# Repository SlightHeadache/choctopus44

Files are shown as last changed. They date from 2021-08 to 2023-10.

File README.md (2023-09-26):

# Choctopus44

*Current version: 2.0*

Choctopus44 is low profile, Choc spaced, optionally hotswappaple 44-key column staggered keyboard with a rotary encoder.
It is loosely based on **[gtips's REVIUNG project](https://github.com/gtips/reviung)**, specifically REVIUNG41, but has deviated from it significantly during its development.

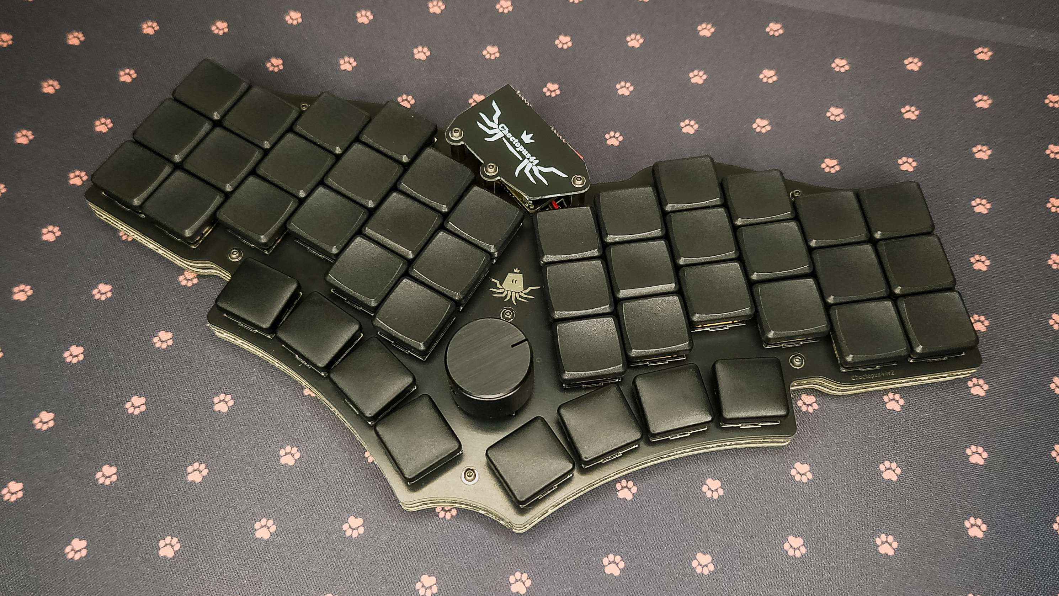
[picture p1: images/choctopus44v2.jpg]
choctopus44


## Known issues with v2

While all the main issues of the original Choctopus44 prototypes were addressed during the development of v2, some new minor arose during it's development.

  * Switch plate does not accommodate all encoders properly. Certain non-Alps THD encoders, and SMD encoders may require filing the plate's encoder cut out to be a little bigger.
    See **[encoder documentation](documents/encoder.md)**.
  * Flaky Bluetooth behaviour in certain edge cases while using Nice!Nano, seems like certain devices don't like Nice!Nano's/ZMK's Bluetooth handling
  * During fabrication with tented vias the battery circuit vias can easily remain exposed, at least with JLCPCB. By my understanding this is caused by the solder mask liquid seeping
    into the via's hole. This doesn't seem to affect other vias as only the battery vias are slightly larger than usual. This should be avoidable by using plugged vias instead, but as
    that increases the cost of manufacturing I'm going to create a hotfix version in the future that shrinks those vias to the standard size to alleviate the issue.

## TODO

  * Add documentation for v2's plate and bottom foams

## Parts list

### Main components

| Part | Count | Optional | Notes |
| --- |:---:|:---:|:-----:|
| PCB | 1 | | |
| Diode [1N4148 SMD or THD] | 45 | | |
| Kailh Choc sockets | 44 | x | |
| Tactile switch TL3342 or compatible | 1 | | Stem height of 1.54mm used in tested builds |
| Slide switch PCM12 or compatible | 1 | x | Only useful if a wireless microcontroller is used in conjunction with a battery |
| EC11 encoder or compatible | 1 | x | See detailed **[encoder documentation](documents/encoder.md)**; Can also be replaced with a Choc or an MX switch |
| ProMicro/Nice!Nano or compatible | 1 | | |
| MCU socket (or header rows) | 1 (2) | x | |
| Kailh Choc key switch | 44 (45) | | |
| 3.7 Volt battery | 1 | x | Only useful if a wireless microcontroller is used |
| 100 nF capacitors (axial or 1206 SMD) | 2 | x | Used in the optional encoder filter circuit |
| 10 kOhm resistors (axial or 1206 SMD) | 4 | x | ***Not adviced!*** Can be used in the encoder filter circuit, but can cause issues at least with Nice!Nanos |

### Case hardware

| Part | Count | Optional | Notes |
| --- |:---:|:---:|:-----:|
| Top plate [PCB] | 1 | | |
| Bottom plate [PCB] | 1 | | |
| M2 stand off 5mm | 9 | | |
| M2 screw 3mm | 15 (18) | | 18 needed if MCU cover is not used |
| Rubber bump ons | ~11 | | Depending on your bump ons you might need to use more, or get away with using fewer |

### Example extra case hardware if using MCU cover

**Note:** The length of the required MCU cover stand-offs is highly dependant on the used battery and its orientation (assuming one is used at all), and the used MCU socket.
With the listed screws and stand offs, a 5mm thick battery can fit between the MCU and the MCU cover without much issue as long as the the MCU socket is slim enough.

| Part | Count | Optional | Notes |
| --- |:-----:|:---:|:-----:|
| M2 stand off 10mm | 3 | | |
| M2 screw 10mm | 3 | | Used for the bottom plate stand offs; 3mm screws used on the MCU cover |

### Misc hardware

| Part | Count | Optional | Notes |
| --- |:---:|:---:|:-----:|
| Choc spacing compatible keycaps (e.g. MBK) | 44 (45) | | |

## Firmware

***Please note!*** Should you utilize a pre-existing QMK/Vial/ZMK set up, you may need to do additional steps not defined here before you can succesfully build the firmware.
Whether or not that's required is highly dependant on the version and the state of your pre-existing set up!

*Pre-built binaries TBA*

 * QMK: https://github.com/SlightHeadache/qmk_firmware : branch `choctopus_project`
   * If you want to utilize your existing QMK set up, navigate to it and run the following `bash` command to fetch and switch to the WIP branch.
     If you are using git via PowerShell or Windows CMD, remember to switch the `&&`s to semicolons. 
     Remember to switch to your preferred local branch if you wish to meddle with other keyboards.
     ```sh
     git remote add choctopus_project git@github.com:SlightHeadache/qmk_firmware.git && git fetch choctopus_project && git checkout --track -b choctopus_project choctopus_project/choctopus_project
     ```
 * Vial: https://github.com/SlightHeadache/vial-qmk : branch `choctopus44-vial`
   * If you want to utilize your existing Vial set up, navigate to it and run the following `bash` command to fetch and switch to the WIP branch.
     If you are using git via PowerShell or Windows CMD, remember to switch the `&&`s to semicolons. 
     Remember to switch to your preferred local branch if you wish to meddle with other keyboards.
     ```sh
     git remote add choctopus44-vial git@github.com:SlightHeadache/vial-qmk.git && git fetch choctopus44-vial && git checkout --track -b choctopus44-vial choctopus44-vial/choctopus44-vial
     ```
 * ZMK: https://github.com/SlightHeadache/zmk : branch `choctopus44`
   * For an easy online build using GitHub actions, fork https://github.com/SlightHeadache/zmk-config and enable Actions from *Settings -> Actions -> Allow all actions*. Then clone your fork.
     The keymap file can be found from path `config/boards/shields/choctopus44/choctopus44.keymap` in the cloned repo. The firmware should now build automagically when you push your keymap changes to GitHub.
     The built firmware can be found from under the GitHub Actions run's summary (e.g. https://github.com/SlightHeadache/zmk-config/actions/runs/6002979887), *not* under either of the build steps.
   * If you want to utilize your existing ZMK set up, navigate to it and run the following `bash` command to fetch and switch to the WIP branch.
     If you are using git via PowerShell or Windows CMD, remember to switch the `&&`s to semicolons. 
     Remember to switch to your preferred local branch if you wish to meddle with other keyboards.
     ```sh
     git remote add choctopus44 git@github.com:SlightHeadache/zmk.git && git fetch choctopus44 && git checkout --track -b choctopus44 choctopus44/choctopus44
     ```

## Build guide

See [build guide](documents/buildguide.md).

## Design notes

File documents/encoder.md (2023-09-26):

# Encoder footprint

## Compatibility

The center encoder footprint in the Choctopus is compatible with EC11 style encoders (both SMD and THD), MX type switches, and Choc switches.
However, certain encoder versions might have issues with the encoder cut out in the switch plate. For example, many SMD encoders and certain THD encoders
with large bodies may not fit the plate cut out properly requiring you to file the plate cut out a bit.
SMD encoders also require you to flatten out the side support legs so that they do not conflict with the switch plate.
Should you do so, please take proper safety percautions, as breathing in FR4 dust is not recommended.

The plan is to slightly adjust the encoder cut out size in version 2.1 to properly accomodate large body encoders. However, even after that SMD encoder
side support legs will still require bending.

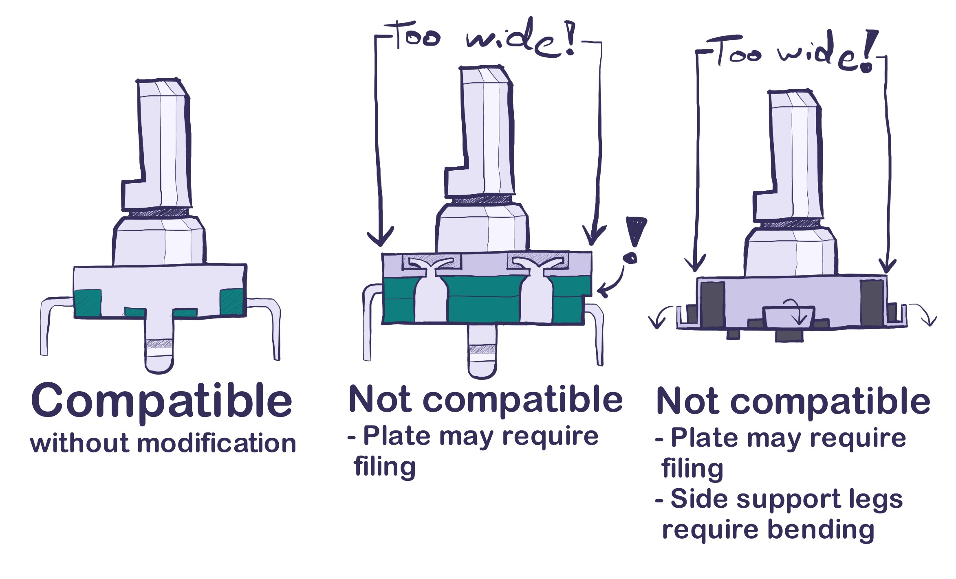
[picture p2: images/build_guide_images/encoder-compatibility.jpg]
encoder compatibility


Largest compatible encoder knob radius is 15mm, though personally I'd recommend going a good bit smaller than that for greater comfort.
However, this is very much down to encoder choise and preference, heavy encoders might be much easier to use with bigger knobs, but lighter ones might be
inconveniently easy to actuate with a large knob.

## Filtering circuit

The encoder footprint is attached to a encoder filtering circuit.
This is intended to improve performance and reliability with lower quality encoders which are not that uncommon.
However, after some very minor testing while building an unit or two it looks like the filtering circuit is largely useless, or even downright harmful for the user experience.
At least based on my testing it looks like ZMK and Nice!Nano do not play nicely with the filtering circuit in it's full configuration,
and that the resistors of the full filter circuit essentially end up disabling it as a whole.
Could be that this is entirely dependant on the values used for the circuit, but at least with 10 kOhm resistors and 100 nF capacitors I had no luck.

In normal operation I would highly recommend just bridging the jumpers that circumvent the filter circuit entirely.
However, based on some rudimentary testing, soldering the capacitors into place may still increase the reliability of the encoder.
At least in my personal board soldering those on seemed to increase the reliability of the encoder from roughly ~95% to ~100%.

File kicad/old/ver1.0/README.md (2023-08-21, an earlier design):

# Note!

This version of the PCB has a lot of problems and is deprecated.

The battery routing issue should be addressed in the latest commit, though that is untested. The USB collision issue still remains.

usb collision issue

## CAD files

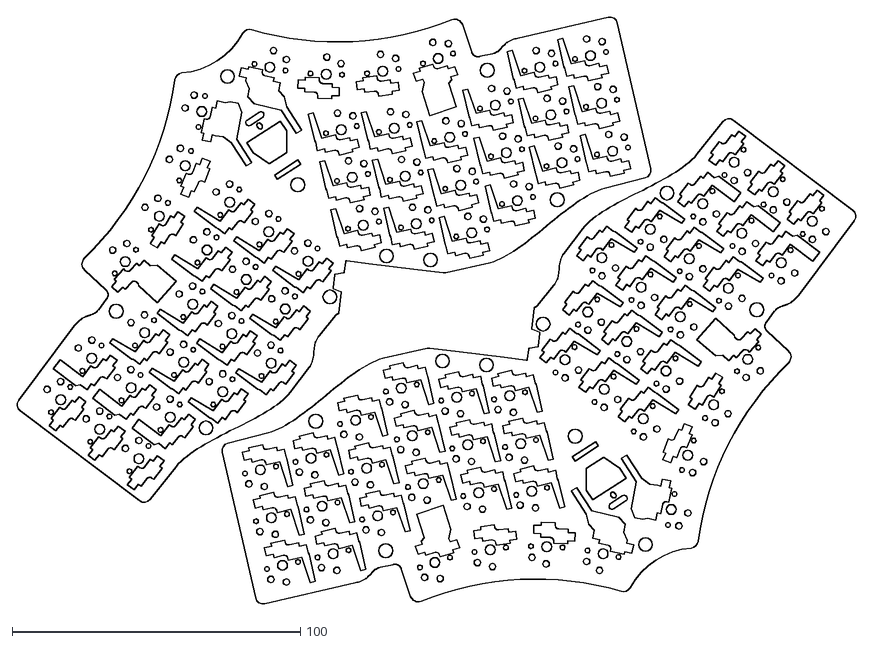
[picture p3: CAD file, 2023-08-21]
kicad/ver2.0/choctopus44-bottom-filler/A4-laser/choctopus44-bottom-filler-Edge_Cuts.dxf
291.7 x 204.0

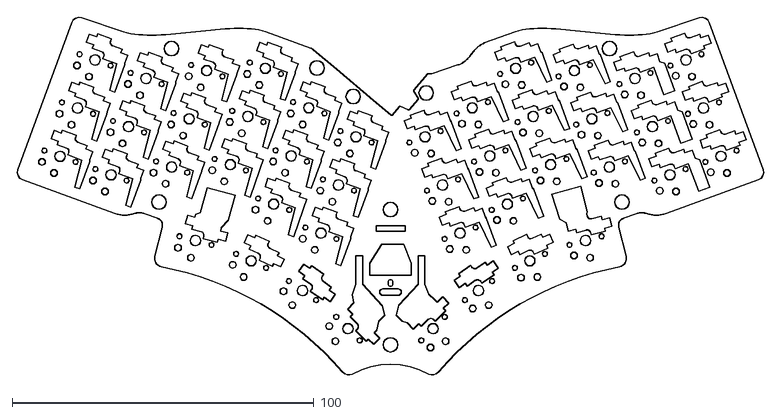
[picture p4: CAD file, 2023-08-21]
kicad/ver2.0/choctopus44-bottom-filler/choctopus44-bottom-filler-Edge_Cuts.dxf
248.1 x 119.1

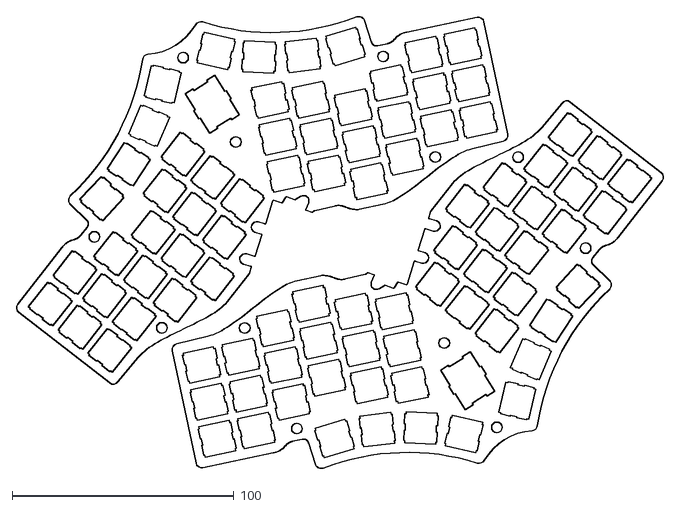
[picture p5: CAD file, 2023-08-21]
kicad/ver2.0/choctopus44-top-filler/A4-laser/choctopus44-top-filler-Edge_Cuts.dxf
292.0 x 203.8

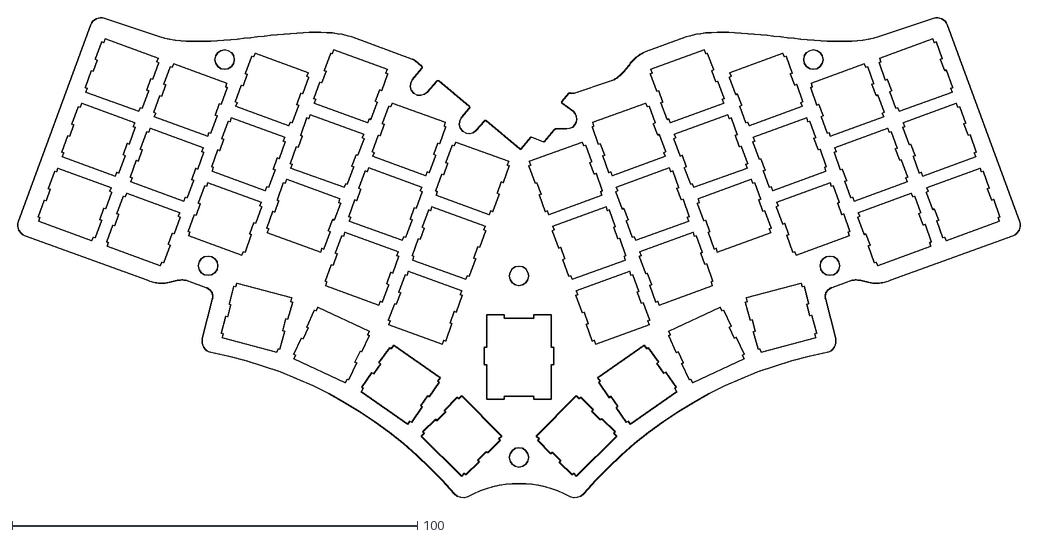
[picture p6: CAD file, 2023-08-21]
kicad/ver2.0/choctopus44-top-filler/choctopus44-top-filler-Edge_Cuts.dxf
248.1 x 119.1

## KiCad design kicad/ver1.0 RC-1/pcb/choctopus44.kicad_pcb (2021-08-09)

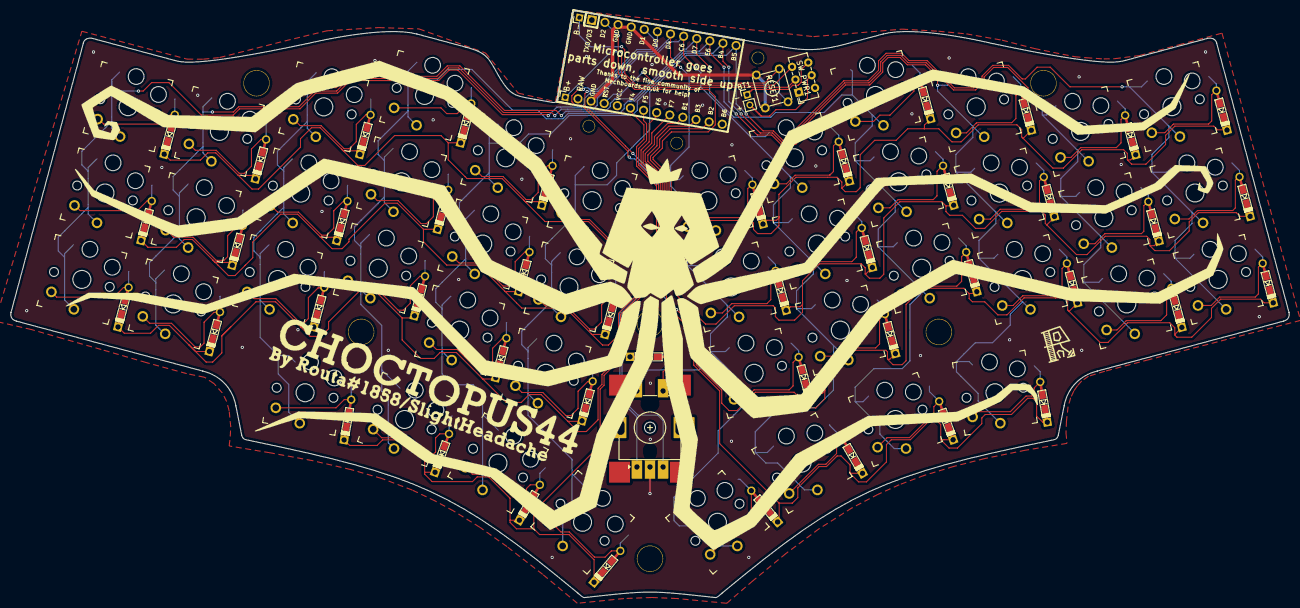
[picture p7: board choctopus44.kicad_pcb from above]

Board: 2 copper layers, 243.9 x 111.9 mm, 105 parts (1 on the bottom side), 67 nets.

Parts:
B+: PinHeader_1x01_P2.00mm_Vertical
B-: PinHeader_1x01_P2.00mm_Vertical
BT1: Battery_Cell; PinHeader_1x02_P2.00mm_Vertical
D1, D2, D3, D4, D5, D6, D7, D8, D9, D10, D11, D12, D13, D14, D15, D16, D17, D18, D19, D20, D21, D22, D23, D24, D25, D26, D27, D28, D29, D30, D31, D32, D33, D34, D35, D36, D37, D38, D39, D40, D41, D42, D43, D44, D45: 1N4148W; Diode-dual
H1: H1; HOLE
H6, H6#2: H6; HOLE
H8, H8#2: H8; HOLE
H11: H11; HOLE
H12: H12; HOLE_2.2mm
H13: H13; HOLE_2.2mm
H14: H14; HOLE_2.2mm
RESET1: SW_PUSH; SW_TH_Tactile_Omron_B3F-10xx
SW1, SW2, SW3, SW4, SW5, SW6, SW7, SW8, SW9, SW10, SW11, SW12, SW13, SW14, SW15, SW16, SW17, SW18, SW19, SW20, SW21, SW22, SW23, SW24, SW25, SW26, SW27, SW28, SW29, SW30, SW31, SW32, SW33, SW34, SW35, SW36, SW37, SW38, SW39, SW40, SW41, SW42, SW43, SW44: SW_PUSH; Kailh_socket_PG1350_optional
SW45: Rotary_Encoder_Switch; RotaryEncoder_Alps_EC11E-Switch_Vertical_H20mm-SMD-support
SW_PWR1: SW_DPST; SW_E-Switch_EG1271_DPDT
U1: ProMicro; ArduinoProMicro

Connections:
+BATT: B+.1, SW_PWR1.1
-BATT: B-.1, SW_PWR1.3
Enc1A: SW45.A, U1.5
Enc1B: SW45.B, U1.6
GND: RESET1.3, RESET1.4, SW45.C, U1.3, U1.4, U1.23
unnamed: BT1.1, SW_PWR1.4
unnamed: BT1.2, SW_PWR1.2
unnamed: D1.2, SW1.2
unnamed: D2.2, SW2.2
unnamed: D3.2, SW3.2
unnamed: D4.2, SW4.2
unnamed: D5.2, SW5.2
unnamed: D6.2, SW6.2
unnamed: D7.2, SW7.2
unnamed: D8.2, SW8.2
unnamed: D9.2, SW9.2
unnamed: D10.2, SW10.2
unnamed: D11.2, SW11.2
unnamed: D12.2, SW12.2
unnamed: D13.2, SW13.2
unnamed: D14.2, SW14.2
unnamed: D15.2, SW15.2
unnamed: D16.2, SW16.2
unnamed: D17.2, SW17.2
unnamed: D18.2, SW18.2
unnamed: D19.2, SW19.2
unnamed: D20.2, SW20.2
unnamed: D21.2, SW21.2
unnamed: D22.2, SW22.2
unnamed: D23.2, SW23.2
unnamed: D24.2, SW24.2
unnamed: D25.2, SW25.2
unnamed: D26.2, SW26.2
unnamed: D27.2, SW27.2
unnamed: D28.2, SW28.2
unnamed: D29.2, SW29.2
unnamed: D30.2, SW30.2
unnamed: D31.2, SW31.2
unnamed: D32.2, SW32.2
unnamed: D33.2, SW33.2
unnamed: D34.2, SW34.2
unnamed: D35.2, SW35.2
unnamed: D36.2, SW36.2
unnamed: D37.2, SW37.2
unnamed: D38.2, SW38.2
unnamed: D39.2, SW39.2
unnamed: D40.2, SW40.2
unnamed: D41.2, SW41.2
unnamed: D42.2, SW42.2
unnamed: D43.2, SW43.2
unnamed: D44.2, SW44.2
unnamed: D45.2, SW45.S1
col0: SW1.1, SW7.1, SW13.1, SW19.1, SW25.1, SW31.1, SW41.1, SW45.S2, U1.7
col1: SW2.1, SW8.1, SW14.1, SW20.1, SW26.1, SW32.1, SW42.1, U1.8
col2: SW3.1, SW9.1, SW15.1, SW21.1, SW27.1, SW33.1, SW37.1, SW43.1, U1.9
col3: SW4.1, SW10.1, SW16.1, SW22.1, SW28.1, SW34.1, SW38.1, SW44.1, U1.10
col4: SW5.1, SW11.1, SW17.1, SW23.1, SW29.1, SW35.1, SW39.1, U1.11
col5: SW6.1, SW12.1, SW18.1, SW24.1, SW30.1, SW36.1, SW40.1, U1.12
reset: RESET1.1, RESET1.2, U1.22
row0: D1.1, D2.1, D3.1, D4.1, D5.1, D6.1, U1.20
row1: D7.1, D8.1, D9.1, D10.1, D11.1, D12.1, U1.19
row2: D13.1, D14.1, D15.1, D16.1, D17.1, D18.1, U1.18
row3: D19.1, D20.1, D21.1, D22.1, D23.1, D24.1, U1.17
row4: D25.1, D26.1, D27.1, D28.1, D29.1, D30.1, U1.16
row5: D31.1, D32.1, D33.1, D34.1, D35.1, D36.1, U1.15
row6: D37.1, D38.1, D39.1, D40.1, D45.1, U1.14
row7: D41.1, D42.1, D43.1, D44.1, U1.2

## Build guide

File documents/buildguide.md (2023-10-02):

# Choctopus44v2 - Build Guide

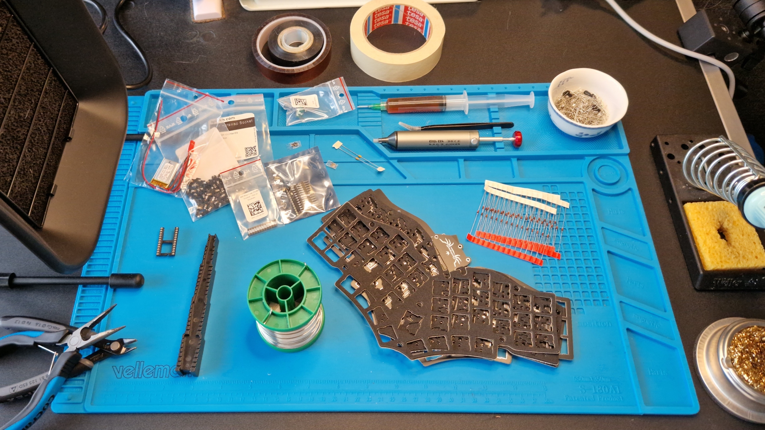
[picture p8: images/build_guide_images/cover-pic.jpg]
cover art


This guide documents the building process of Choctopus44v2 with THD diodes and capacitors, hotswap sockets, and an encoder.

## PCB inspection

Before starting the assembly process I recommend quickly inspecting the PCB for any defects.
The vias in the battery and Vcc traces are bigger than other vias on the board.
This can cause the solder mask to seep into it during fabrication leaving the via exposed and conductive on the surface,
especially if using JLCPCB's tented option for via covering. This is something to be addressed in the next version of the board.

Should you encounter a via like that I recommend covering the via with something non-conductive,
e.g. Kapton tape, as is done in the image in the *Battery* section.

## Diodes

Regardless of the type of diodes it's recommended that diodes are mounted on the bottom side of the PCB. In fact, if you're building be
board with case foams mounting the diodes on the bottom side of the PCB is required.
Be mindful of the orientation of the diodes, especially of the encoder diode and the two four-diode clusters.

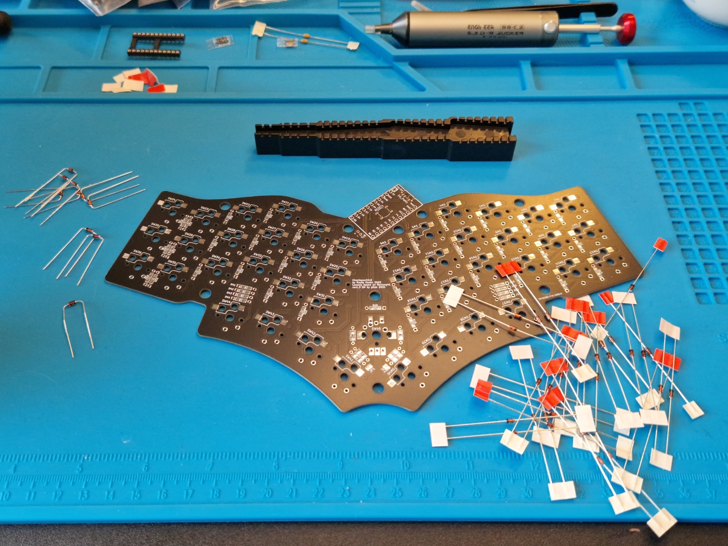
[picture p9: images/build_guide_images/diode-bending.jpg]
bent diodes


Here in the guide I'm using a PCB holder which enables me to solder the THD diodes from the "bottom" side without bending any legs.
It's not necessary to use one but I find it less cumbersome.

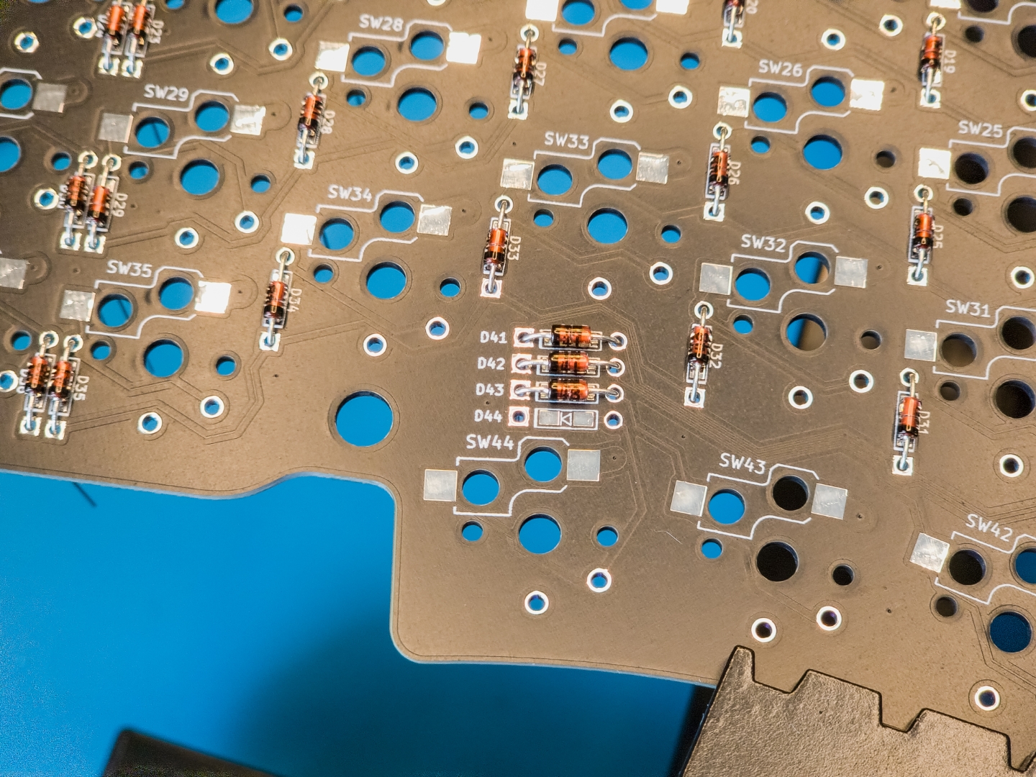
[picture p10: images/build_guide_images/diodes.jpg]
placed diodes


After soldering the diodes, cut the diode legs. It's recommended to cut the legs as flush as possible especially if using a plate foam.

## Encoder jumpers and capacitors

If you plan on using an encoder in your build it's recommended that you bridge the encoder filter jumpers **JP1** and **JP2** instead of using the full
encoder filter circuit. In testing I noticed that ZMK/Nice!Nano doesn't seem to like the resistors that the full filter circuit would utilize.
Please refer to **[encoder documentation](encoder.md)** for further details.

### Jumpers

The jumpers can be drag soldered rather easily by just applying a small blob of solder to the tip of your soldering iron and dragging it from
one jumper pad to another. Your mileage may wary depending on your soldering iron and soldering wire. Please keep in mind that the jumper pads
seem to be a bit more heat sensitive than one might expect, I've managed to boil one jumper pad off before noticing that drag soldering seems
to work the best for them. Should you manage to do the same you can work around the issue by using a bent diode leg or a small piece of wire to
bridge **R3** resistor footprint for jumper **JP1**, and **R2** for jumper **JP2**. ***DO NOT*** bridge resistors **R1** or **R4**.

### Capacitors (optional)

Especially if using cheap and noisy knock-off encoders the encoder output can occassionally be messy, leading to missed or double actuations when rotating it.
If that's a concern I recommend soldering on the capacitors **C1** and **C2** to the encoder filtering circuit. Even if it's not a concern it's easy enough to
solder them along with the jumpers, they do not seems to have any downsides.

The capacitors are soldered in the same way as the diodes. The capacitors used here don't have a polarity, so you don't have to worry about the orientation that they're installed.

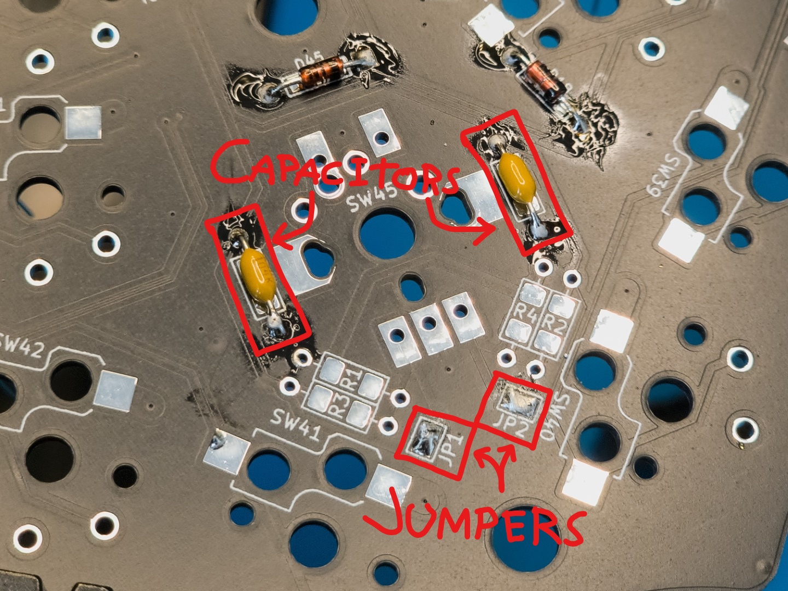
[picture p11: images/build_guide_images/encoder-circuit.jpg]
jumpers and capacitors


### Resistors (**not recommended!**)

It is possible to forgo bridging the jumpers and solder on the resistors of the encoder filter circuit as well.
This is not recommended and may cause the encoder to stop giving reliable output. See **[encoder documentation](encoder.md)** for further details.

## Hotswap sockets

This step is only necessary when building the board in hotswap configufation.

My preferred method of soldering hotswap sockets is to
  - First apply solder on one of the socket's pads
  - Then put the socket on top of the tinned pad
  - Reflow the tinned pad while pushing down on the socket with something
  - Appy solder to the other end of the socket
  - Finally apply more solder on the first pad if deemed necessary

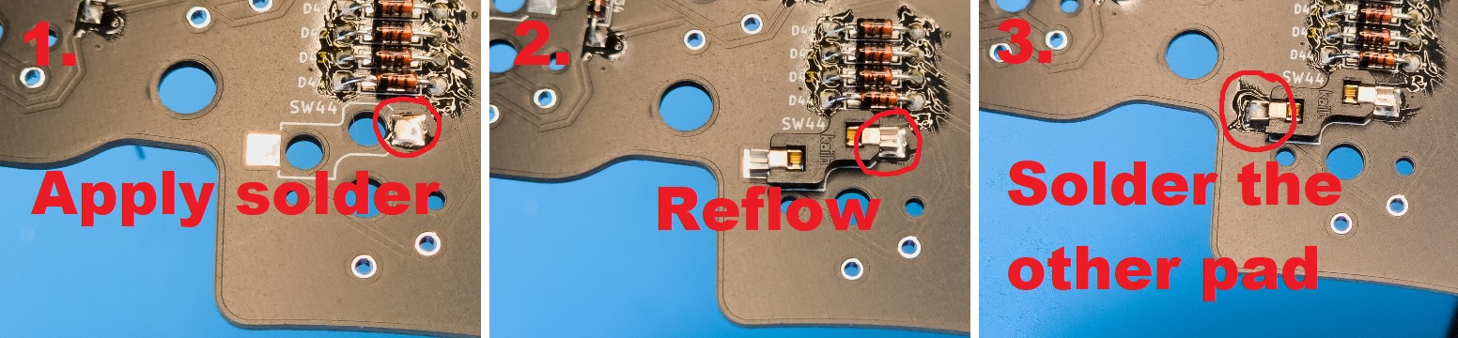
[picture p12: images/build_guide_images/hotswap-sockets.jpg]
hotswap sockets


## Reset switch

Reset switch is a bit trickier to solder than the hotswap sockets, but is not too dissimilar of a process.
  - First apply solder to one of the reset switch pads
  - Hold the reset switch with tweezers and reflow the tinned pad so that one of the reset switch legs gets soldered
  - Apply solder to the rest of the legs

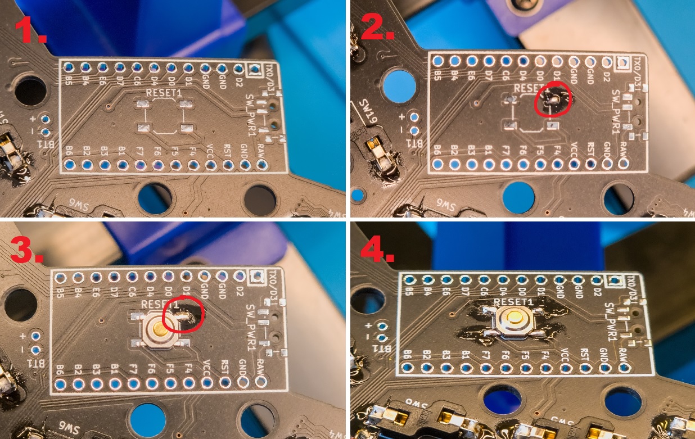
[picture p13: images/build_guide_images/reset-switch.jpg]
reset socket


## Power switch (optional)

This step is only necessary if building a battery powered unit. The process is very similar to the reset switch step, only slightly trickier.

For the small powered pins it might be helpful to apply a small blob of solder to the tip of your iron and just dab that on the pin,
instead of trying cram both the soldering wire and the solderin iron into a small working area.

  - First apply solder to one of the power switch pads
  - Hold the power switch with tweezers and reflow the tinned pad so that one of the reset switch legs gets soldered
  - Apply solder to the rest of the legs

After soldering the switch make sure that none of the three powered pins are shorted to the side support legs or each other.

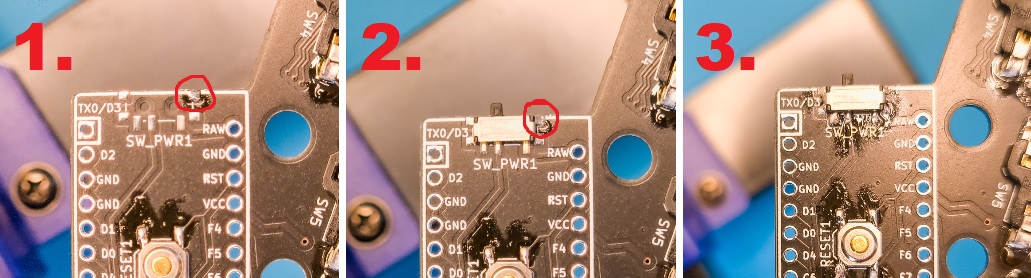
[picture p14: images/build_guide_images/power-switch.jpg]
power switch


## MCU socket / MCU

After soldering all the components on the bottom side of the PCB it's sensible to start soldering components of the top side of the PCB.
In my opinion it's best to start this with the MCU socket or the MCU as that's the slimmest top side component. If you're using a socket
it's convenient to use tape to keep it in place while soldering.

If you're soldering the MCU directly onto the PCB it might make sense to actually solder the battery leads into place before the MCU.
That way it's easier get the battery leads tucked neatly under the microcontroller.

Whether you're socketing or soldering the microcontroller **it is crucial that the controller is installed smooth side up!**

Especially if you're not socketing the microcontroller it's probably the most convenient to flash the controller before soldering it into place.

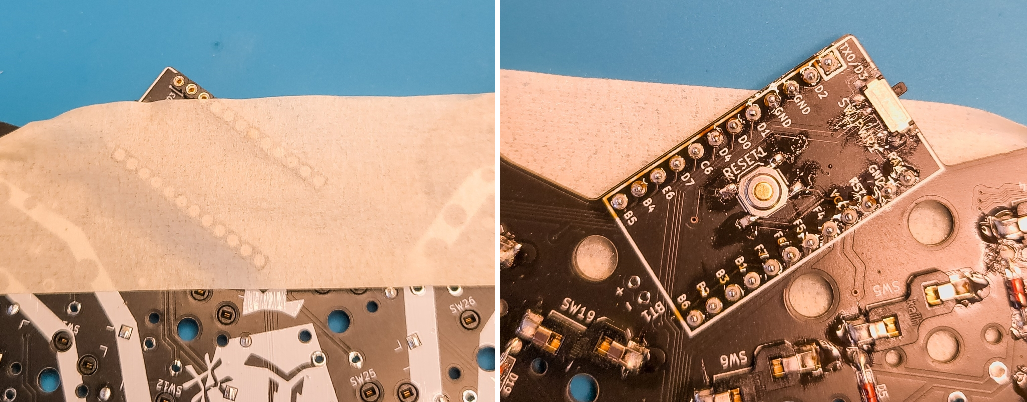
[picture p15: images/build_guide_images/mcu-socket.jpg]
mcu socket


## Encoder

If you're building the board with an encoder I recommend soldering it into place before putting in the switches.
If you're using a switch in the center position instead solder that into place when installing switches.

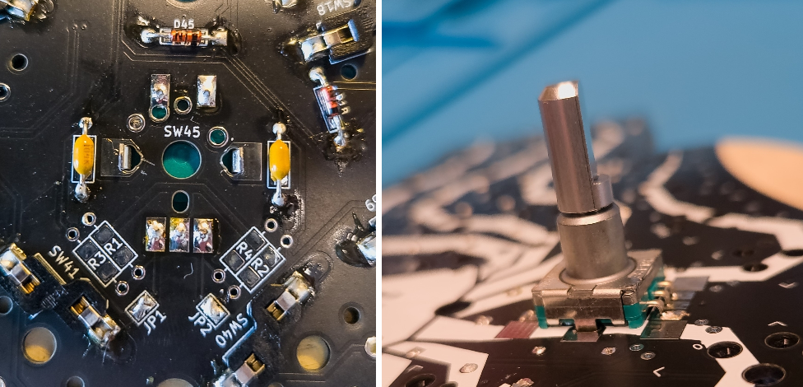
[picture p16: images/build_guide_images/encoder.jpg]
encoder


If you're using an SMD encoder or an encoder with an unusually large body it might be necessary to file the edges of the encoder cut out in the switch plate.
Please take proper safety cautions when doing so, FR4 dust is not good for your lungs. Additionally, with SMD encoders the curled side support legs have to be rolled flat.
Please refer to **[encoder documentation](encoder.md)** for further details.

encoder compatibility

## Battery (optional)

If you're using a battery with your build it's possible to solder it to the PCB's battery pins instead of the MCU's own battery pins. This can make the build look a lot cleaner.

Depending on how long your battery leads are you might need to shorten them for a cleaner fit. Optimally you should be able to fit the loose battery leads under the microcontroller.

You should choose a battery that's small enough to fit under the MCU cover neatly.
It can be helpful to add a small piece of double sided tape between it and the MCU so that it sits securely and doesn't wobble.

***Notes!***
  1. Be mindful of the battery polarity! Incorrect polarity might damage your device
  2. I recommend having the power switch in the "off" position (top position) when soldering in the battery. That prevents the circuit of being properly powered while soldering.
  3. Try to not short the battery pins. The battery pins are a bit closer than might be convenient.
     I managed to get a small spark when soldering in the battery during the documentation build,
     which thankfully didn't break anything, but is nonetheless something that one should pay attention to.

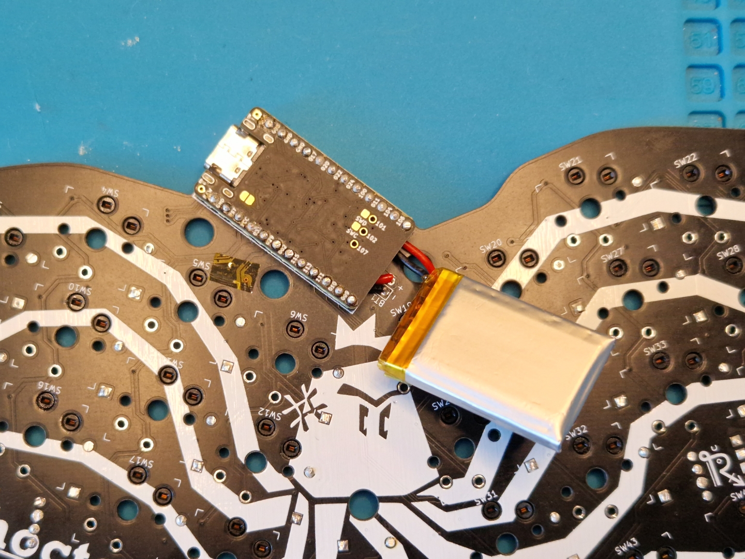
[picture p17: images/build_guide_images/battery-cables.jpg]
battery


## Switches

Break the MCU cover off of the switch plate. The small "bridges" attaches to the mouse bites might be a bit difficult to remove by hand, if you have trouble with those I'd recommend
gripping them with pliers for better leverage. The tolerance between the switch plate and the MCU is pretty tight, depending on your MCU and its headers/socket you might have
to file the broken off mouse bites just a little bit if you have clearance issues. Please take proper safety cautions when doing so, FR4 dust is not good for your lungs.

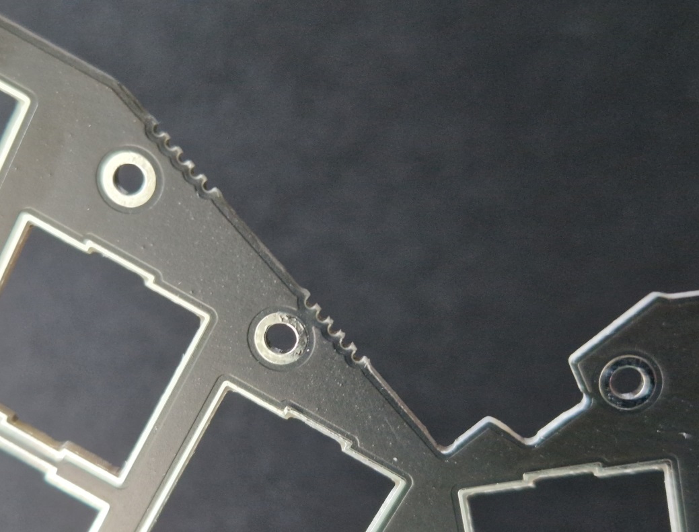
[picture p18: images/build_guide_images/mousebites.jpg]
mousebites


If you're using a plate foam, install it as a part of this phase. If you're using a battery it might be necessary to trim the foam just a bit
near the battery pads to make more room for the battery cables depending on your configuration.
Additionally, if you have an adhesive plate foam and plan to use it without gluing it into place I would recommend trimming the edges of the backing paper so they don't stick out as much.

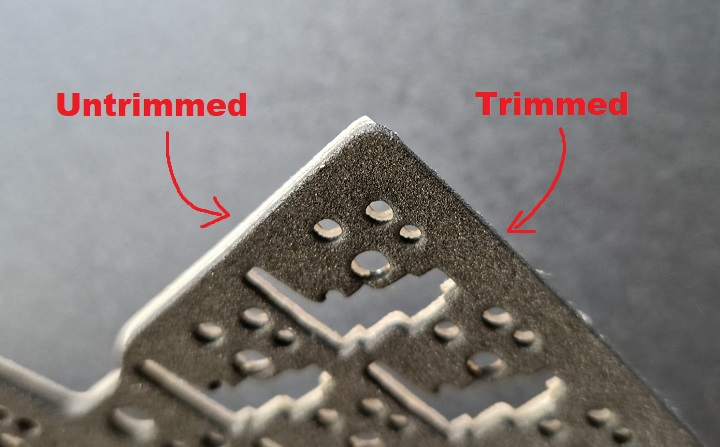
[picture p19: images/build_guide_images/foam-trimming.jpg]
trimmed foam


### Hotswap

Install the switches into the plate/PCB stack one by one. Be mindful of not using too much force so you don't damage the switches or worse, the switch sockets.

hotswap sockets

### Solder

Install the switches into the switch plate, and solder them into place.

## Physical assembly

Install 6 5mm stand offs on the top side of the bottom plate using 3mm screws. Install 3 other 5mm stand offs for the MCU cover positions using 10mm screws.
After the stand offs, install the bottom foam if you have one. Same as with the plate foam, if you have an adhesive bottom foam and plan to use it without
gluing it into place I would recommend trimming the edges of the backing paper so they don't stick out as much.

Install the PCB/plate assembly on top of the bottom plate using 6 3mm screws in the main positions.

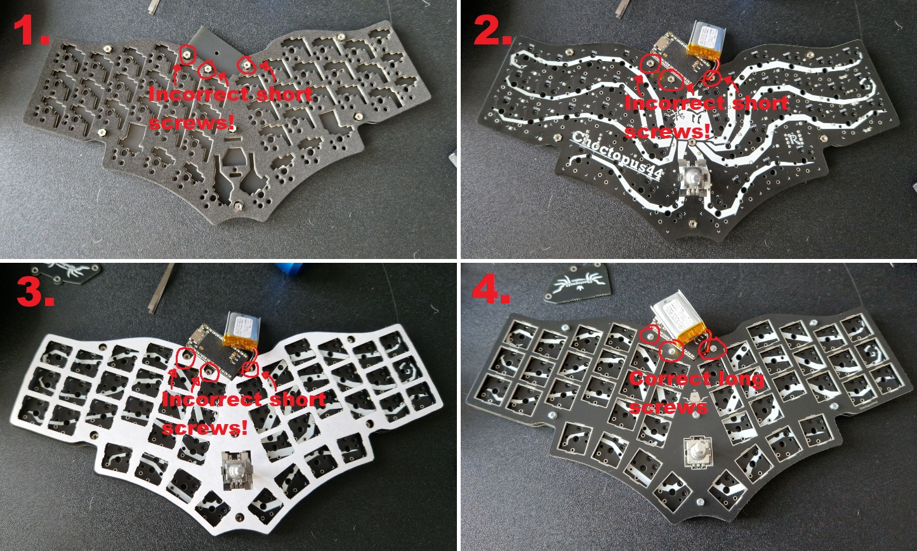
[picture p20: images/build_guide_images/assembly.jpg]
physical assembly


Install 10mm stand offs on the MCU cover screw bits pointing through the switch plate. After that install the MCU cover using 3mm screws.

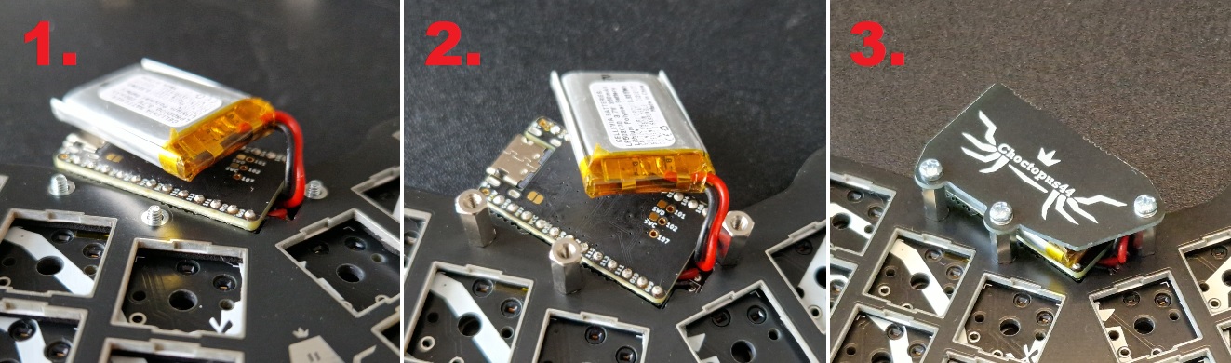
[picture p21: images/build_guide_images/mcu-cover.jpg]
mcu cover


Install bump ons on the bottom of the keyboard.

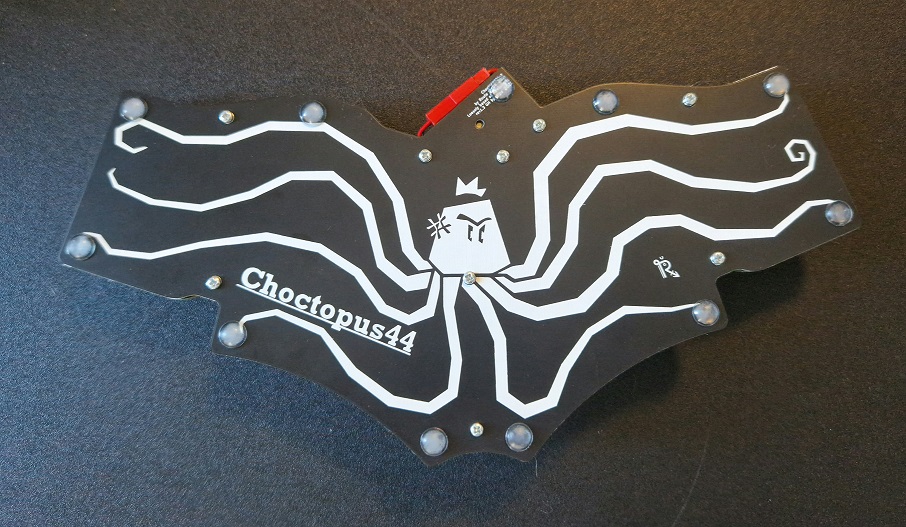
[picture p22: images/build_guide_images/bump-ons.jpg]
bump ons


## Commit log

2021-08-29 Revise documentation
    * Add documentation about slide switch issues
    * Add documentation about USB plug collision issue
    * Add build guide
    * Fix wording issues
2021-09-13 Emphasized warning of issues in the current revision
2021-11-01 Initial restructuring for revision 1.0.1
    - Add link to new build guide
    - Might include some of the changes in Envious-Data's PR
    [choctopus44-B_Cu.gbl, choctopus44-B_Mask.gbs, choctopus44-B_Paste.gbp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]
2022-01-15 RC1, filtering circuit
    [choctopus44-B_Cu.gbl, choctopus44-B_Mask.gbs, choctopus44-B_Paste.gbp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]
2022-01-16 backups etc
    [choctopus44.kicad_sch]
2022-01-18 Schema done, PCB work restarted
    [choctopus44.kicad_sch]
2022-01-24 PCB work started for RC-1
    [choctopus44.kicad_sch, choctopus44.sch]
2022-02-04 todo: adjust component positions and reroute everything
    [choctopus44.kicad_sch]
2022-02-04 clean up some ground planes and silk screen orientations
2022-07-12 revise ver1.0 RC-1 routing; remove redudant backups
    [choctopus44.kicad_sch]
2023-09-26 Update firmware section of Readme, add missing encoder filter parts to parts list
